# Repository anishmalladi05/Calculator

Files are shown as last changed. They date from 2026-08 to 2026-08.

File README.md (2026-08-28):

# Calculator
16 key calculator with a 128 by 32 pixel display and low profile choc switches. Uses circuit python. I made it to challenge myself and use a screen in my builds. I also wanted to try choc switches without building a whole keyboard.

## Assembly:
Look at the assembly video in the repo
<br></br>
Step 1:
<br></br>
Solder PCB components on
<br></br>
Step 2:
<br></br>
Assemble it into case according to the video

## Flashing:
To flash, press BOOT on the board, and while pressing boot, press reset, then release reset, and THEN release boot
<br></br>
Upload the UF2 File into the drive called RP1-RP2
<br></br>
Open the drive called CIRCUITPY
<br></br>
Delete everything in there
<br></br>
Replace it with everything in the folder called code so it looks like this:
<br></br>
Screenshot 2026-08-28 at 12 14 24 PM (2)
<br></br>
Enjoy!

## Images:
Screenshot 2026-08-28 at 12 24 07 PM

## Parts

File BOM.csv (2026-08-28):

Item | "Link" | "Price"
16x choc switches: | https://www.amazon.com/KAILH-Official-Chocolate-Mechanical-Keyboard/dp/B0B3MN1ZLW | "$19"
1x 128x32 OLED panel (needs to allow for 5v): | https://www.amazon.com/dp/B079BN2J8V?lv=shuf&channelId=500&plpRedirect=mhFallback&th=1 | "$8"
16x Keycaps (Can buy own, or 3d print files are in the CAD folder): | https://www.amazon.com/Chocolate-Mechanical-Keyboard-Transparent-1U-40Pcs/dp/B0CP28G897 | "$23"
1x SEEEDUINO XIAO RP2040: | https://www.seeedstudio.com/Seeed-Studio-XIAO-ESP32S3-Pre-Soldered-p-6334.html | "$4"
1x Ability to solder: | Please provide yourself | "Free!"
1x PCB (found in PCB files, it is the zip file): | jlcpcb.com | "$4"
1x UCB-C cable to connect to device: | https://www.amazon.com/Amazon-Basics-Charger-480Mbps-Certified/dp/B01GGKZ2SC?sp_csd=d2lkZ2V0TmFtZT1zcF9hdGY | "$10"
1x Coding skills (only if you want to customize): | Please provide yourself | "Free again!"
1x 3D printer with 1 spool filament: | https://us.store.bambulab.com/products/a1-mini?from=navigation | "$220"
2x Socket head cap screws SHCS.M316-50: | https://www.mcmaster.com/products/cap-screws/fastener-head-type~socket/?matchtype=p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 | "$5"

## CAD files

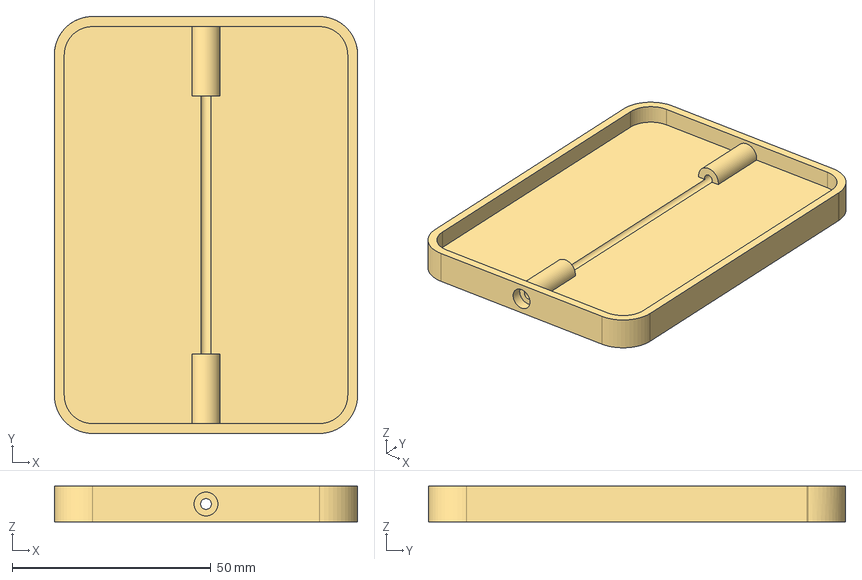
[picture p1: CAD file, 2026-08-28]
CAD/Calculator bottom.step
76.4 x 105.0 x 9.00 mm

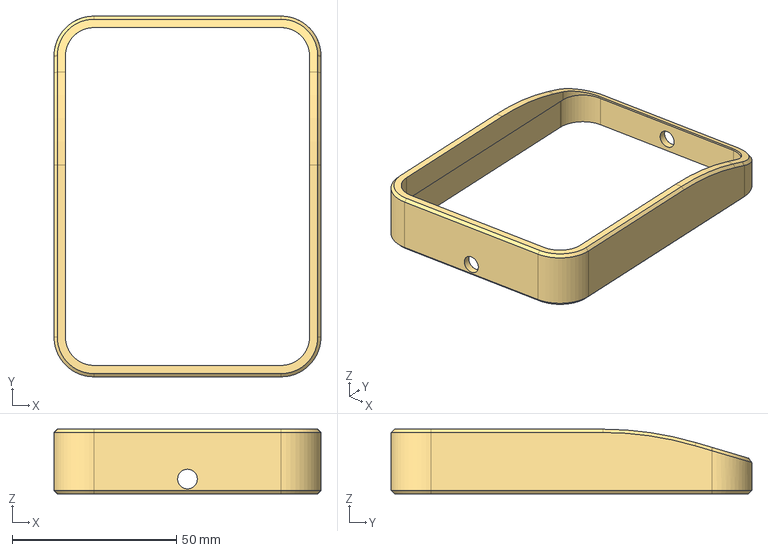
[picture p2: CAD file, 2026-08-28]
CAD/Calculator top.step
81.4 x 110.0 x 19.7 mm

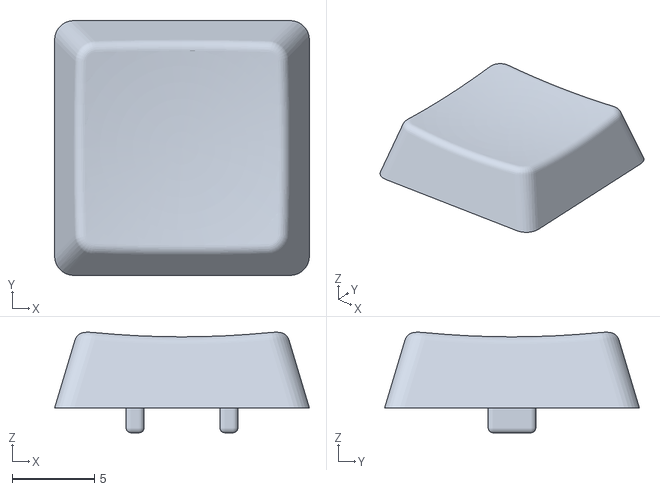
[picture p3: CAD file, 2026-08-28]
CAD/cap.stl
15.5 x 15.5 x 6.12

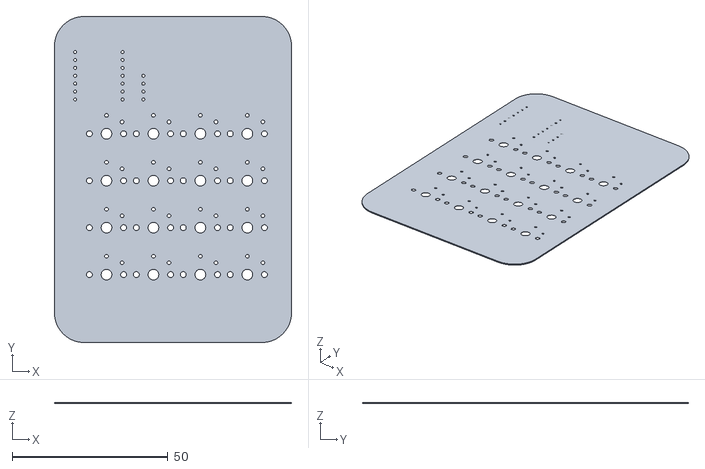
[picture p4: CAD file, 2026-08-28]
CAD/cover.stl
76.2 x 104.8 x 0.4

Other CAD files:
CAD/Bottom.stl
CAD/Calculator cap.step
CAD/Calculator cover.step
CAD/Top.stl

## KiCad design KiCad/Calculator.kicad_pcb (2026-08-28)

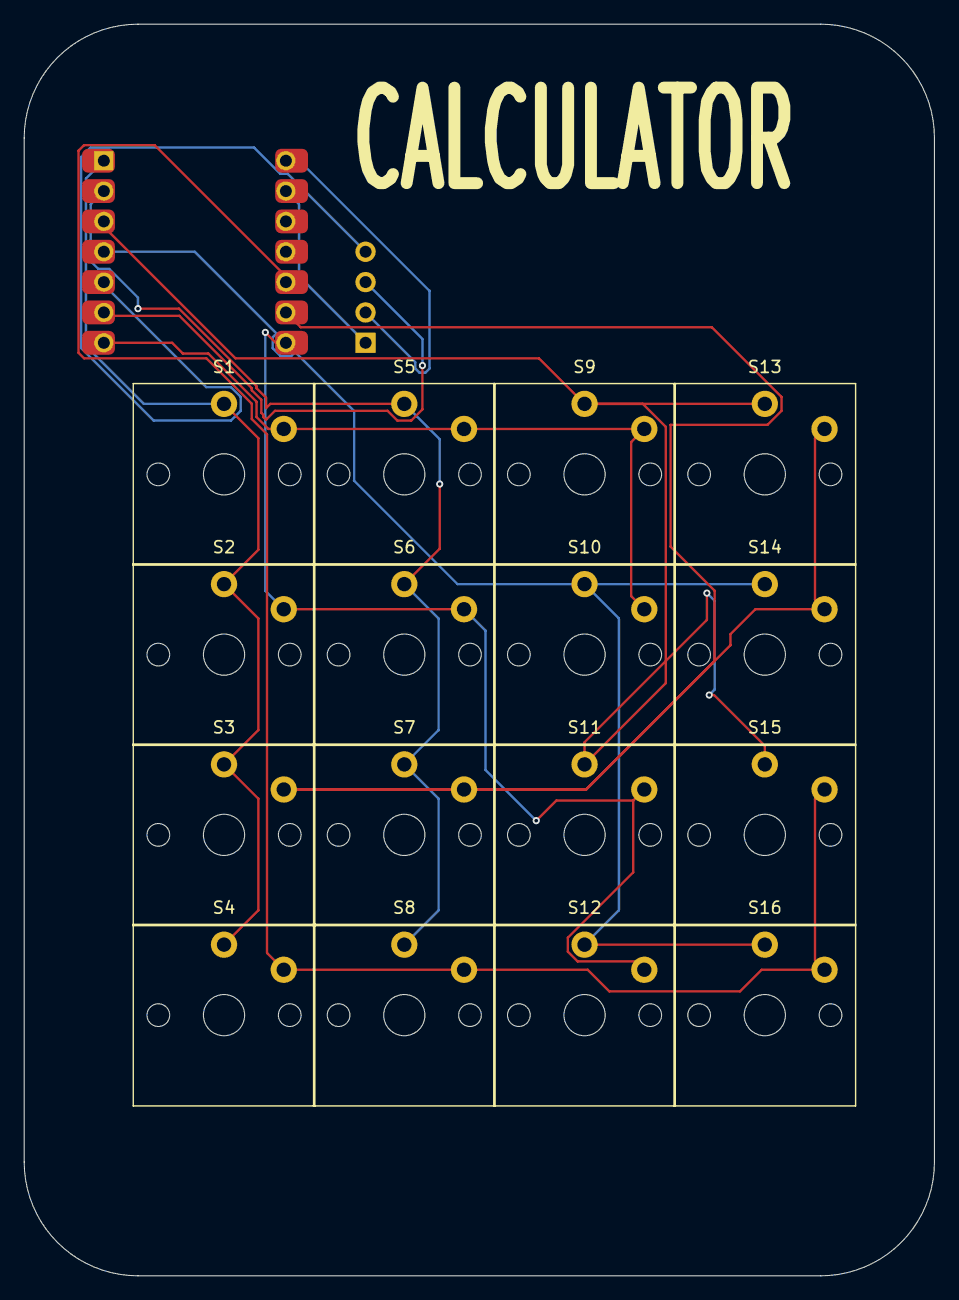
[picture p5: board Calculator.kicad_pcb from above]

Board: 2 copper layers, 76.2 x 104.8 mm, 18 parts (0 on the bottom side), 12 nets.

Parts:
J1: OLED_128x32
S1, S2, S3, S4, S5, S6, S7, S8, S9, S10, S11, S12, S13, S14, S15, S16: Choc_V1_1.00u
U1: MCU_Seeed_XIAO_RP2040; Seeed_XIAO_RP2040

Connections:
1: S1.1, S2.1, S3.1, S4.1, U1.1 (PA02_A0_D0)
2: S5.1, S6.1, S7.1, S8.1, U1.2 (PA4_A1_D1)
3: S9.1, S11.1, S13.1, S15.1, U1.3 (PA10_A2_D2)
4: S10.1, S12.1, S14.1, S16.1, U1.4 (PA11_A3_D3)
5V: J1.2 (VCC), U1.14 (5V)
7: S1.2, S5.2, S9.2, S10.2, U1.7 (PB08_A6_D6_TX)
8: S2.2, S6.2, S11.2, S12.2, U1.8 (PB09_A7_D7_RX)
9: S3.2, S7.2, S13.2, S14.2, U1.9 (PA7_A8_D8_SCK)
10: S4.2, S8.2, S15.2, S16.2, U1.10 (PA5_A9_D9_MISO)
GND: J1.1 (GND), U1.13 (GND)
SCL: J1.3 (SCL), U1.6 (PA9_A5_D5_SCL)
SDA: J1.4 (SDA), U1.5 (PA8_A4_D4_SDA)

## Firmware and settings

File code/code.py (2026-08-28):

import time
import board
import busio
import digitalio
import adafruit_ssd1306

# Setup I2C display (SDA = D4/GP8, SCL = D5/GP9)
i2c = busio.I2C(board.SCL, board.SDA)
display = adafruit_ssd1306.SSD1306_I2C(128, 32, i2c)

# Clear display
display.fill(0)
display.text("Calc Ready", 0, 12, 1)
display.show()

# Pin mapping based on schematic:
# Rows 1-4: D0 (GP2), D1 (GP4), D2 (GP10), D3 (GP11) -> Remember GP1 is D0
row_pins = [board.D0, board.D1, board.D2, board.D3]
# Cols 1-4: D7 (GP9), D8 (GP8), D9 (GP7), D10 (GP6) -> wait, let's map matching schematic labels:
# S1-S4 connect to pins 7, 8, 9, 10 on the right side:
# Looking at U1: Pin 7=PB08_A6_D6_TX, Pin 8=PB09_A7_D7_RX, Pin 9=PA7_A8_D8_SCK, Pin 10=PA5_A9_D9_MISO, Pin 11=PA6_A10_D10_MOSI
# Let's use standard digitalio setup for the 4 rows (outputs/inputs) and 4 columns.
# Rows: Pins 1, 2, 3, 4 (D0, D1, D2, D3)
# Cols: Pins 7, 8, 9, 10 (D6, D7, D8, D9 or similar mapping)

rows = [digitalio.DigitalInOut(p) for p in [board.D0, board.D1, board.D2, board.D3]]
cols = [digitalio.DigitalInOut(p) for p in [board.D6, board.D7, board.D8, board.D9]]

for r in rows:
    r.direction = digitalio.Direction.OUTPUT
    r.value = False

for c in cols:
    c.direction = digitalio.Direction.INPUT
    c.pull = digitalio.Pull.DOWN

# Keypad layout mapping (4x4)
keys = [
    ['1', '2', '3', '+'],
    ['4', '5', '6', '-'],
    ['7', '8', '9', '*'],
    ['C', '0', '=', '/']
]

current_input = ""
expression = ""

def update_display(text):
    display.fill(0)
    display.text("Calc:", 0, 0, 1)
    display.text(text[:16], 0, 16, 1) # Limit to 16 chars for 128x32 screen
    display.show()

def get_key():
    for r_idx, row in enumerate(rows):
        row.value = True
        for c_idx, col in enumerate(cols):
            if col.value:
                row.value = False
                time.sleep(0.2) # debounce
                return keys[r_idx][c_idx]
        row.value = False
    return None

update_display("0")

while True:
    key = get_key()
    if key:
        if key == 'C':
            current_input = ""
            expression = ""
            update_display("0")
        elif key == '=':
            try:
                # Evaluate expression safely
                result = str(eval(expression + current_input))
                update_display(result)
                expression = ""
                current_input = result
            except Exception:
                update_display("Error")
                current_input = ""
                expression = ""
        elif key in ['+', '-', '*', '/']:
            if current_input:
                expression += current_input + key
                current_input = ""
                update_display(expression)
        else:
            current_input += key
            update_display(expression + current_input)

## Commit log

2026-08-28 added everything
    [Bottom.stl, Calculator bottom.step, Calculator cap.step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]
2026-08-28 Update and rename BOM-3.csv to BOM.csv
    [BOM-3.csv, BOM.csv]
